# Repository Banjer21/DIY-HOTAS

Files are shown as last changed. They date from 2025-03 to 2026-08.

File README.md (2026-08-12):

# DIY HOTAS 

The files need to be cleaned up a bit. 

## Getting started
The files contain multiple copies of the parts. They are somewhat logically named, _org or _empty mean that these parts are original, or have no attachement points.
They are just shells, these you can edit for your own convenience. The parts are made for specific components, which might not be optimal but do work. <br>

## Thingiverse

The 3d files will also be uploaded to thingiverse once I have finalised exporting the latest versions.
Check out my [thingiverse](https://www.thingiverse.com/banjer21/designs) for some old designs I made. I will upload some more 3d models like the buttons and switches used in this project.

## Issues

If you have any problems or questions, feel free to post them [here](https://github.com/Banjer21/DIY-HOTAS/issues).

## License

CC BY 4.0 https://creativecommons.org/licenses/by/4.0/

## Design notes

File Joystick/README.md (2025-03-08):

# Files
There are two joysticks, a left handed and a right handed joystick. If the VGA 9 pin connector is mounted properly, both sticks can be attached to one gimbal.

The files are the version as how I printed them. Meaning there are screw holes and other additions specific to certain buttons/PCBs.

The button caps might need to be adjusted depending on your printers accuracy. They should be a nice pressure fit. 

## Updates
Please have patiens as not all files will be added at the same time. When I made the project I did not really have the intention to make it public, but since there seems some interest I have decided
to make it public. This means some files need to be cleaned up or updated to work without needing to modify them afterwards.

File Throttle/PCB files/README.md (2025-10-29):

Gerber files for the PCB of the right throttle. This is the only pcb at the moment. I might add more.

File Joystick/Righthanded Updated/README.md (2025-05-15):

These files were edited by Reddit user ADDicT10N.
The changes are mostly for a more easier print and assembly. As initially the model was made to account for a smaller print bed (150mmx150mm). 
These files are suitable for a larger printbed.

The files with [B21] are unchanged, the files with [ADD] have been modified.

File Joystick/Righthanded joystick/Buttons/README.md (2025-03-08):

# Buttons

This folder contains the STLs for the headswitches and buttons. These should be modified to fit your printers tolerance.

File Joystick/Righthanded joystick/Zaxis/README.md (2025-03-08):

# Z axis

This folder contains all STLs for the Z axis.

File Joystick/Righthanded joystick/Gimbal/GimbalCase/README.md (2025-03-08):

# Gimbal case

This folder contains all the files for the case containing the gimbal.

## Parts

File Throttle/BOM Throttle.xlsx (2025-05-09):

BOM Throttle
Component name | Description | quantity | Note
Throttle Base
Hall effect sensors | 49E | 2 | https://nl.aliexpress.com/item/4000723242353.html
Bearing | 688zz | 5 | https://nl.aliexpress.com/item/4001139691289.html
Resistor | 10K ohm | 2
Micro controller | Arduino due | 1 | For throttle
Micro controller | Arduino micro | 1 | For joystick
Connector to joystick | Gx12 5 pin male and female | 1 | https://nl.aliexpress.com/item/1005005927302832.html
Pushbuttons | 12x12x7.3 mm | 13 | https://nl.aliexpress.com/item/32855079668.html
magnets | 5x1 mm circular | 40 | https://www.amazon.nl/dp/B07T13H3R5?ref=ppx_yo2ov_dt_b_fed_asin_title
IO expanders base | PCF8575 io expander board | 3
Base to Throttle connector | GX12 7 pin | 2 | https://nl.aliexpress.com/item/32970360099.html
Bearing | 608zz | 6
Throttle limit switch | limit switch | 4 | https://nl.aliexpress.com/item/32802664696.html
Flipswitches | on-on | 14 | https://nl.aliexpress.com/item/1005003582611455.html
Eject button | Push button | 1 | https://nl.aliexpress.com/item/4000904962561.html
Rotary switch | 8x8x5 push button | 5 | https://nl.aliexpress.com/item/4000681640116.html
USB port | USB B port | 1 | https://nl.aliexpress.com/item/32834923469.html
Flipswitch Flaps | on-off-on | 1 | https://nl.aliexpress.com/item/1005003568092031.html
Flipswitch | on-off-on | 1 | https://nl.aliexpress.com/item/1005005954429095.html
resistors | 10K ohm | 26 | normal through hole resistors
capacitors | 100nF | 26 | normal through hole capacitors
rotary encoders | rotary encoder with button | 7 | https://nl.aliexpress.com/item/32839106848.html
Button | latching button 8x8x8mm,6 pin | 2
stepper motor | 5v 4 fase stepper motor | 2 | Currently not wired in my build, purely to provide resistance, but can be used for force feedback
RGB led | ws2812b 5050smd | 3 | https://nl.aliexpress.com/item/1005002518781334.html
RGB led | ws2812D | 26
Right Throttle
IO expanders Right throttle | PCF8575ts | 2 | https://nl.aliexpress.com/item/1005006137714412.html
Hatswitches | 10x10x10 mm 5 way switch | 5 | https://nl.aliexpress.com/item/4000681560472.html
Button | 6x6x5 mm | 1 | https://nl.aliexpress.com/item/32887215534.html
Joystick | ps4 joystick | 1 | https://nl.aliexpress.com/item/1005005976145560.html
resistors | 10K ohm 0805 | 29 | https://nl.aliexpress.com/item/32847143167.html
capacitors | 100nF 0805 | 29 | https://nl.aliexpress.com/item/32812155708.html
springs | 13/64 x 13/16 | 2 | https://nl.aliexpress.com/item/1005008623524403.html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
Flipswitch | on-off-on | 1 | https://nl.aliexpress.com/item/1005005954429095.html
PCB throttle
Left Throttle
IO expanders left throttle | PCF8575 io expander board | 1
resistors | 10K ohm | 7 | normal through hole resistors
capacitors | 100nF | 7 | normal through hole capacitors
springs | 13/64 x 13/16 | 2 | https://nl.aliexpress.com/item/1005008623524403.html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
Hatswitch | 10x10x10 mm 5 way switch | 1 | https://nl.aliexpress.com/item/4000681560472.html
Button | 6x6x5 mm | 2 | https://nl.aliexpress.com/item/32887215534.html
Potentiometer | 10K ohm | 1 | https://nl.aliexpress.com/item/32827236711.html
Flipswitch | on-off-on | 1 | https://nl.aliexpress.com/item/1005003568092031.html
Misc
Screws m3 | 10mm,20mm | enough | https://nl.aliexpress.com/item/1005003619368620.html
Screws m2 | 10mm,6mm | enough | https://nl.aliexpress.com/item/1005003619368620.html
variaty of axels | 8 mm, 3mm

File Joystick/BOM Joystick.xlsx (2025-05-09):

BOM Joystick
Component name | Description | quantity | Note
Joystick Gimbal
Hall effect sensor xy axis | 49E | 2 | https://nl.aliexpress.com/item/4000723242353.html
Bearing | 688zz | 5 | https://nl.aliexpress.com/item/4001139691289.html
Bearing | 623zz | 3 | https://nl.aliexpress.com/item/4001139691289.html
Resistor | 10K ohm | 2
Micro controller | Arduino nano | 1 | To collect all signals including the analog axis- if the break lever or z axis is not used and no RGB leds are used, only an arduino micro can be used
Micro controller | Arduino micro | 1
Connector to throttle | Gx12 5 pin male and female | 1 | https://nl.aliexpress.com/item/1005005927302832.html
Connector to Stick | RS232 female | 1
springs | 23/64 x 1 3/8 | 4 | https://nl.aliexpress.com/item/1005008623524403.html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
magnets | 5x1 mm circular | 14 | https://www.amazon.nl/dp/B07T13H3R5?ref=ppx_yo2ov_dt_b_fed_asin_title
Joystick
Connector to gimbal | RS232 male | 1
Hall effect sensor z axis/break lever | 49E | 2 | https://nl.aliexpress.com/item/4000723242353.html
Bearing | 6802RS | 2 | https://nl.aliexpress.com/item/4000519932015.html
Pink button | 6x6x5 mm | 1 | https://nl.aliexpress.com/item/32887215534.html
thumb hat switch | 10x10x10 mm 5 way switch | 1 | https://nl.aliexpress.com/item/4000681560472.html
Primary trigger button | 6x6x5 mm | 2 | https://nl.aliexpress.com/item/32887215534.html
primary trigger spring | 11.4 mm length 4.4 mm width 0.3mm thickness | 1
Front panel hatswitch | 10x10x9 mm smd 5 way switch | 2 | https://nl.aliexpress.com/item/4000681535647.html
Front panel push button | 12x12x7.3 mm | 2 | https://nl.aliexpress.com/item/32855079668.html
resistors | 10K ohm 0805 | 28 | https://nl.aliexpress.com/item/32847143167.html
capacitors | 100nF 0805 | 28 | https://nl.aliexpress.com/item/32812155708.html
IO expander | PCF8575ts | 2 | https://nl.aliexpress.com/item/1005006137714412.html
Thumb joystick | ps4 joystick | 1 | https://nl.aliexpress.com/item/1005005976145560.html
Index hatswitch | 10x10x10 mm 5 way switch | 1 | https://nl.aliexpress.com/item/4000681560472.html
Secondary trigger | limit switch | 2 | https://nl.aliexpress.com/item/32802664696.html
secondary trigger spring | 7/32 x 11/16 | 1 | https://nl.aliexpress.com/item/1005008623524403.html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
pcb connectors | zh1.5 |  | https://nl.aliexpress.com/item/32764328358.html
RGB led | 4020 90 degree | 8 | https://nl.aliexpress.com/item/10000009330139.html
RGB led | ws2812b 5050smd | 9 | https://nl.aliexpress.com/item/1005002518781334.html
RGB led | ws2812D | 2 | make sure the pin out is correct from flat side: data in-GND-5V-data out
magnets z axis | 5x1 mm circular | 5 | https://www.amazon.nl/dp/B07T13H3R5?ref=ppx_yo2ov_dt_b_fed_asin_title
Z axis spring |  | 1 | obtained from a microsoft sidewinder precision 2 joystick
variaty of axels | 8 mm, 3mm
PCB front panel
PCB triggers
PCB LED | optional

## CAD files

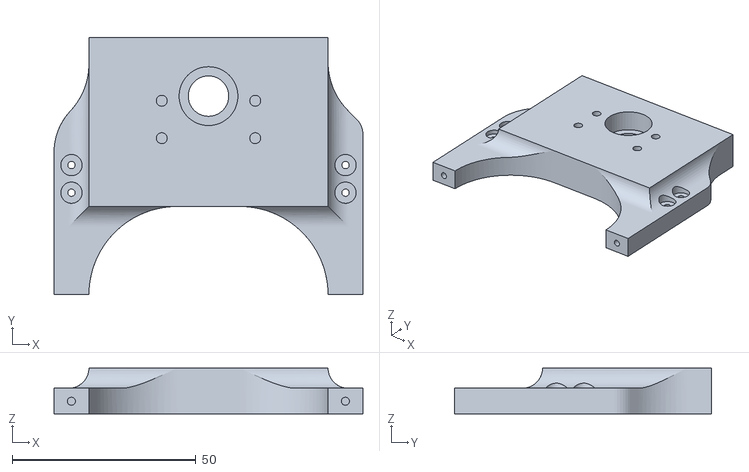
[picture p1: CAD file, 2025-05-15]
Joystick/Righthanded Updated/Gimbal/MainFrame Back [B21] [ADD].stl
84.0 x 70.0 x 12.5

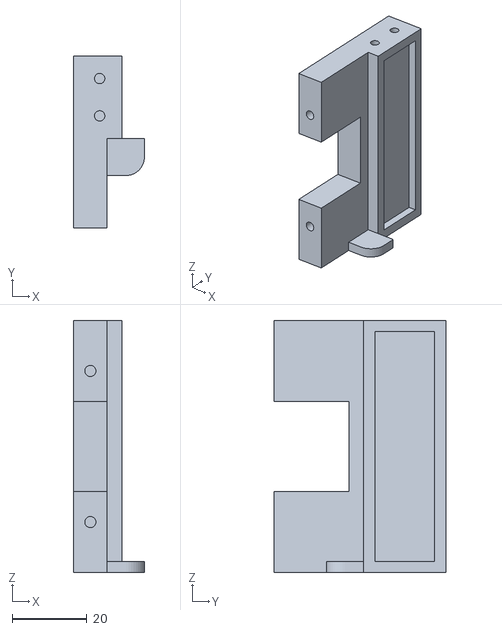
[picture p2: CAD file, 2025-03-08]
Joystick/Righthanded joystick/Gimbal/MainFrame Right.stl
19.0 x 46.0 x 67.5

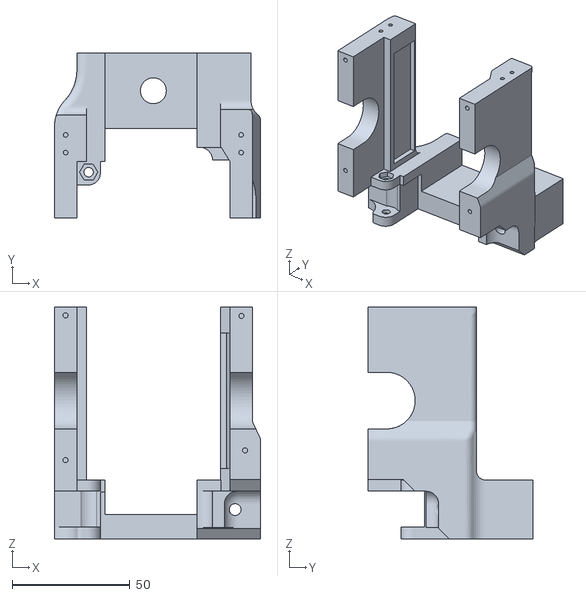
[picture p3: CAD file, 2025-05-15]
Joystick/Righthanded Updated/Gimbal/MainFrame Front [B21] [ADD].stl
87.5 x 70.0 x 98.5

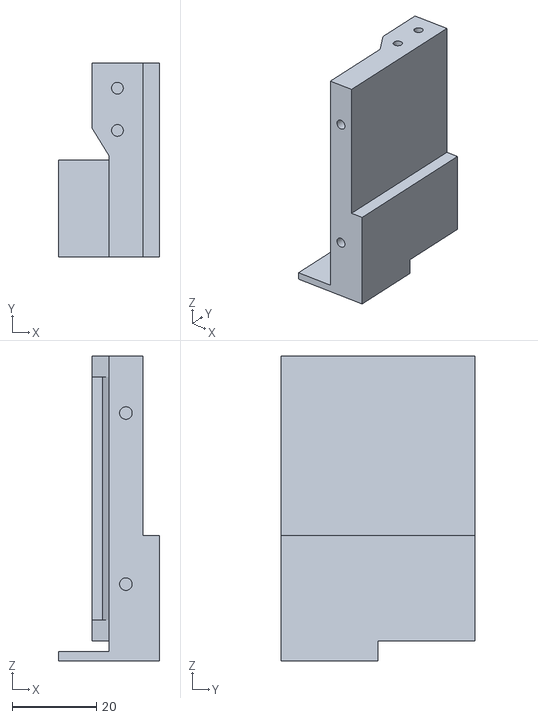
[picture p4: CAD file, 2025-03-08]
Joystick/Righthanded joystick/Gimbal/MainFrame Left.stl
24.0 x 46.0 x 72.2

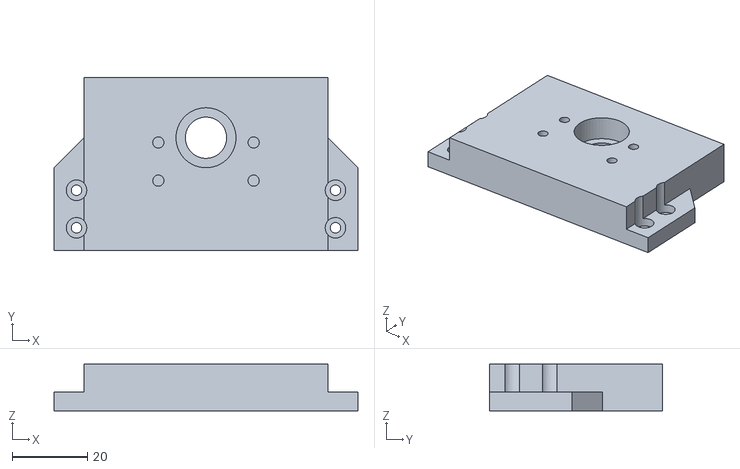
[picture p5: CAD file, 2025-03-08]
Joystick/Righthanded joystick/Gimbal/MainFrame Back.stl
81.0 x 46.0 x 12.5

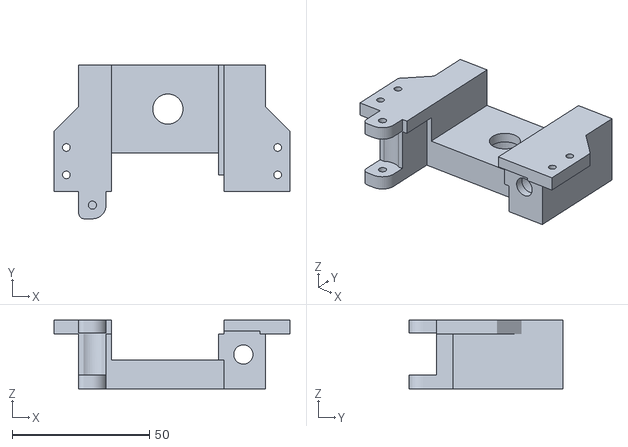
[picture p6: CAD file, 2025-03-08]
Joystick/Righthanded joystick/Gimbal/MainFrame Front.stl
86.0 x 56.0 x 25.0

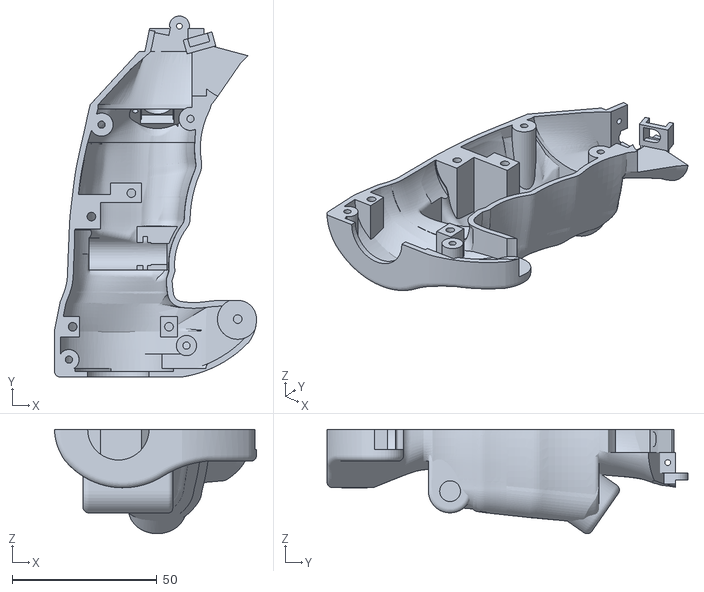
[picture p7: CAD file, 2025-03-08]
Joystick/Righthanded joystick/Body/LeftSide R.stl
69.8 x 124.7 x 36.0

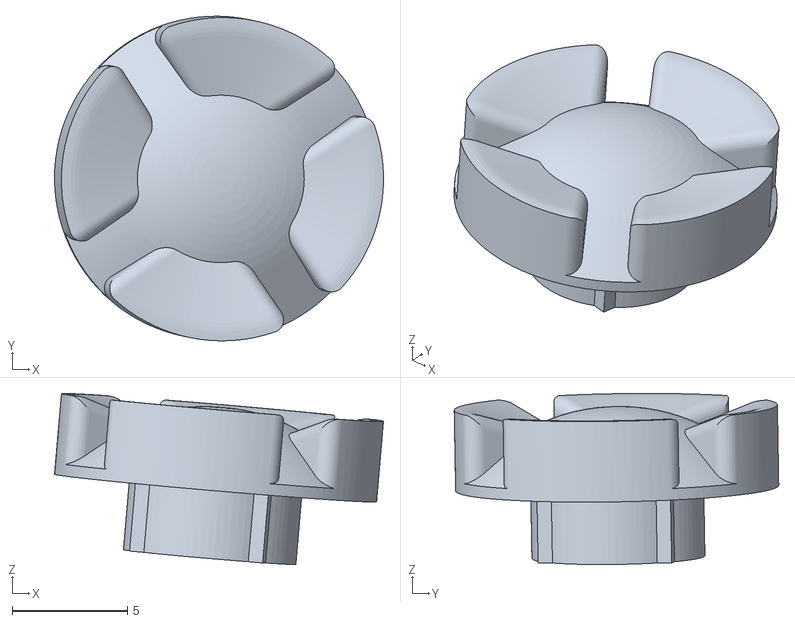
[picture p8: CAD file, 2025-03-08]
Joystick/Righthanded joystick/Buttons/HS Index.stl
14.2 x 14.1 x 7.41

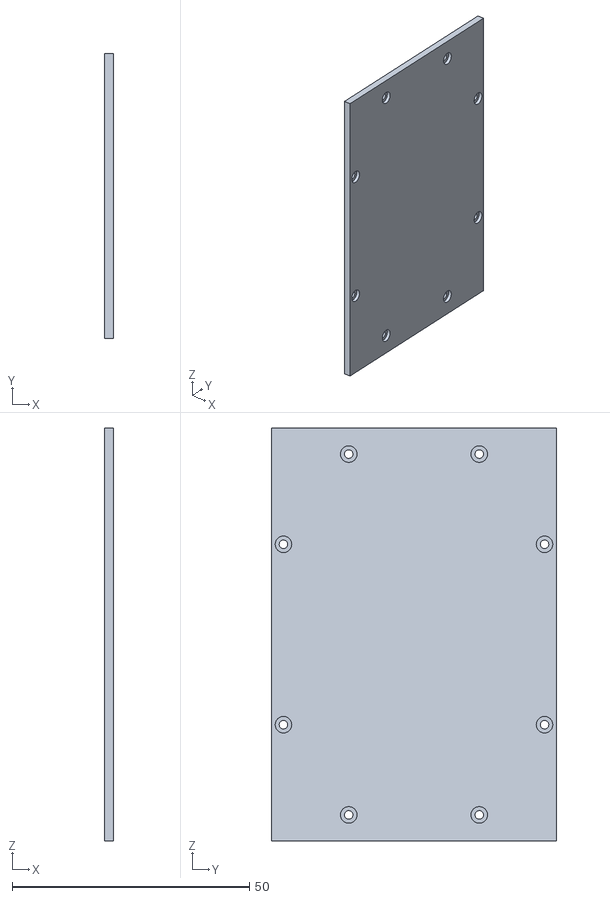
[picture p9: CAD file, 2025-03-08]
Joystick/Righthanded joystick/Gimbal/GimbalCase/Case_Back.stl
2.00 x 60.0 x 87.0

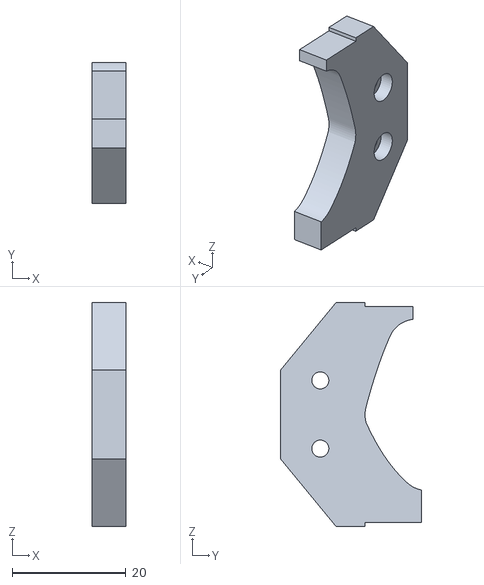
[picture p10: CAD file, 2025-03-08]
Joystick/Righthanded joystick/Gimbal/YCam2.stl
6.00 x 24.8 x 39.4

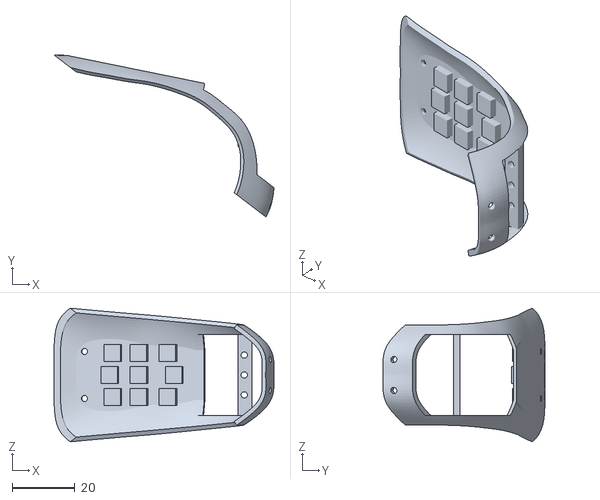
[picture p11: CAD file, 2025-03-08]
Joystick/Righthanded joystick/Head/Diffuser.stl
70.2 x 51.7 x 42.6

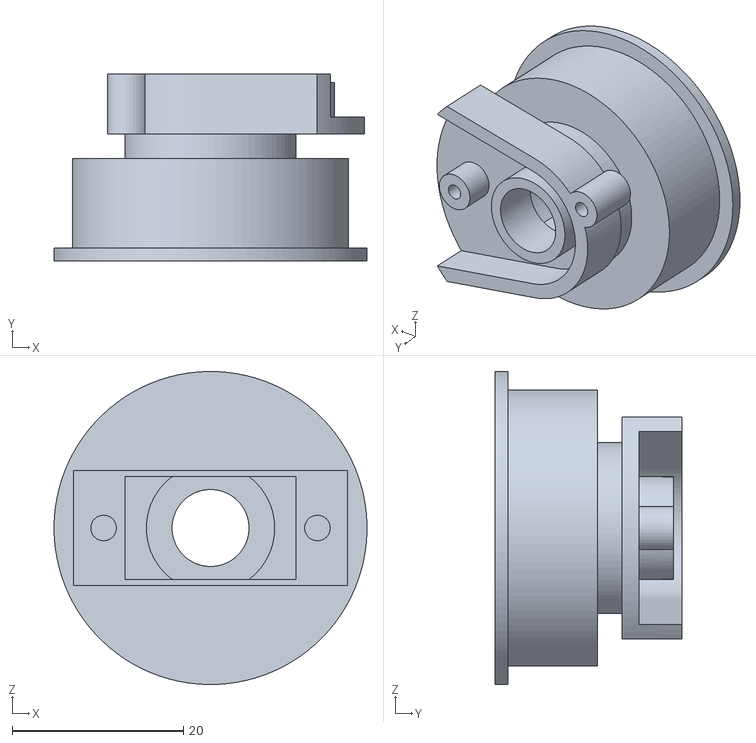
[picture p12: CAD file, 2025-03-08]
Joystick/Righthanded joystick/Zaxis/Zaxis Connector Top.stl
36.6 x 21.9 x 36.6

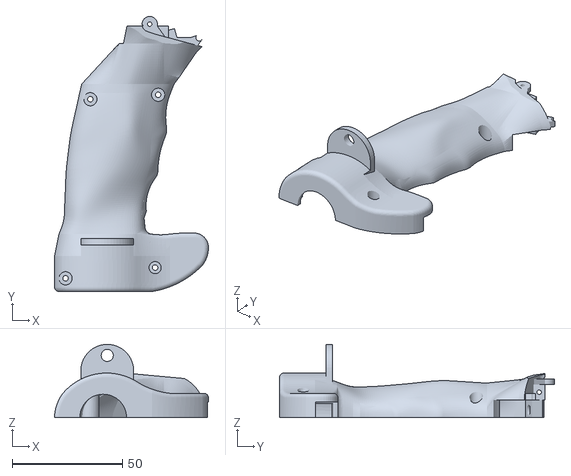
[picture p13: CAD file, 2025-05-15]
Joystick/Righthanded Updated/Body/RighSide R New [B21] [ADD].stl
69.8 x 124.6 x 33.2

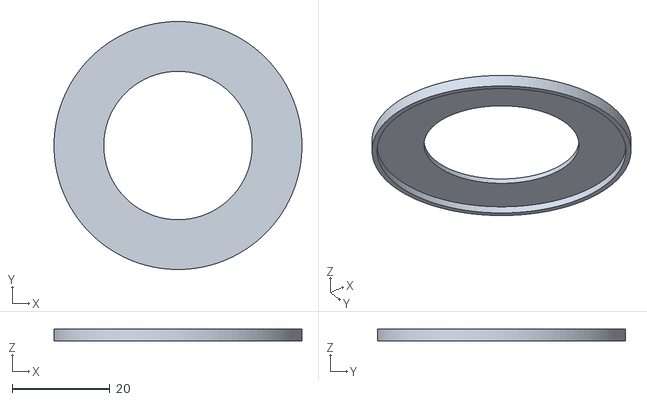
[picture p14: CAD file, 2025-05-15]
Joystick/Righthanded Updated/Gimbal/GimbalCase/Large Ring [B21] [ADD].stl
50.8 x 50.8 x 2.40

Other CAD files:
Joystick/Righthanded Updated/Gimbal/Xaxis Arm V2 [B21] [ADD].stl
Joystick/Righthanded Updated/Head/Toggle Switch Housing V3 [B21] [ADD].stl
Throttle/ThrottleBase Deskmount.step
XY-stage.step
Joystick/Righthanded Updated/Body/Brake Lever [B21] [ADD].stl
Joystick/Righthanded Updated/Body/LeftSide R New [B21] [ADD].stl
Joystick/Righthanded Updated/Body/Momentary Trigger [B21 [ADD].stl
Joystick/Righthanded Updated/Body/PinkyButton [B21] [ADD].stl
Joystick/Righthanded Updated/Body/Thumb Hat 1 [ADD].stl
Joystick/Righthanded Updated/Body/Thumb Hat 2 [ADD].stl
Joystick/Righthanded Updated/Gimbal/Gimbal Shaft [B21] [ADD].stl
Joystick/Righthanded Updated/Gimbal/GimbalCase/Case Back [B21] [ADD].stl
Joystick/Righthanded Updated/Gimbal/GimbalCase/Case Front [B21] [ADD].stl
Joystick/Righthanded Updated/Gimbal/GimbalCase/Case Left [B21] [ADD].stl
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

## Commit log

2025-02-13 Add files via upload
    Fusion360 file of the Right handed Joystick and XY stage
2025-02-13 XY stage step files
    [XY-stage.step]
2025-02-13 Joystick Step
    Righthanded Joystick step files without the PCB models
2025-04-23 Step file of the Throttle
2025-04-23 Throttle Step file
2025-10-29 Create README.md for throttle PCB files
    Add README for right throttle PCB Gerber files.
2025-10-29 Add files via upload
    Added the pcb files for the right throttle
    [throttlerlidpcb_capping.gbr, throttlerlidpcb_copper_signal_bot.gbr, throttlerlidpcb_copper_signal_top.gbr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]
